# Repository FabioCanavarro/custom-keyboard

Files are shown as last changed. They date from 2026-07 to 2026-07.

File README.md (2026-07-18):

# Fool's Deck

My custom 65% mechanical keyboard designed from scratch for the Hack Club hardware grant.

| Phase | Date(s) | Time Spent |
| :--- | :---: | ---: |
| Brainstorming & Ideation | July 2 | 1 hr 0 mins |
| Physical Layout (KLE) | July 2 | 1 hr 10 mins |
| PCB Design (KiCad) | July 2 – July 4 | 5 hrs 59 mins |
| 3D Modeling (Onshape) | July 4 – July 5 | 4 hrs 25 mins |
| Total Build Time |  | 12 hrs 34 mins (15 hrs 34 mins, check notes below) |

> Note: Post submit, I realized I sent the wrong bom file so I made the bom file and updated the pcb art, I spent around 3 hours in total? (but I forgot to add photos, so Idk if it can be considered)

> Hours spent is based calculated based on the time difference of each screenshots, as normally I take one when starting and when ending.
> For more specific hours/day tracking, head over to the [Journal dump](journaldump.md) file

## Keyboard Layout



## Keyboard Case

### Top View



### Isometric View



## PCB View

### With PCB Art



### Without PCB Art



## Schematic View



## Specs

- Brain: Raspberry Pi Pico (RP2040)

- Switches: Boba U4T

- Keycaps: Blank White DSA

- Forehead: 0.91" OLED screen + EC11 Rotary Encoder (knob)

## What I built

I made a custom 65% layout with a 5-key macro column on the left (for dev shortcuts) and a "forehead" on the top right for an OLED screen and a knob.

For the case, I went with a 3D-printed tray mount design. It has a bottom tub with 6mm pillars for the PCB to sit on, and a 1.5mm top switch plate that drops right in. I also cut a window in the top plate to expose the Pico and leave room to wire up the OLED.

## Why I built it

I type a lot and wanted a board that actually fits my workflow. But mostly, I just wanted to figure out how hardware actually works. I know how to code, but I had no clue how physical switches turn into keypresses or how to use CAD without the physics engine yelling at me. I wanted to build the whole stack from the circuit board up to the plastic case.

## What I learned

This was a massive learning curve.

- I learned that MX switches need exactly 5mm of gap between the PCB and the switch plate to clip in properly. I almost crushed my Pico because I didn't account for the height of the header pins, which is why I ended up cutting a display window for it in the top plate so it could fit.

- When making the switch plate, I kept accidentally extruding 70 floating cubes instead of a solid plate. I learned how to use projection tools to draw a proper boundary wall around the keys so the software knows what's solid plastic and what's empty space.

- This project has also taught me a lot about Computer Aided Design, specifically in OnShape. 

## Next up

While the PCB and parts are shipping, I'm going to write the firmware in Rust using the RMK framework so I can get the OLED visualizer and knob working.

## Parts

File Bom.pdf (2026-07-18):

No. Name | Notes | Quantity | Price Per Unit | Cost | Total | Link
1 | Orpheus Pico Microcontroller | Hack Club provided | 1 | 0 | 0 | https://hackclub.com/
2 | Lord of the Mysteries Cat
3 | GATERON MILKY YELLOW -
4 | 1N4148 Through-hole
| Klein Concept Keycaps | 140+ Pcs Officially Licensed | 1 | 69.9 | 69.9 | https://www.oriloot.com/products/lotm-cat-klein-concept-keycaps-140-pcs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
| Mechanical Switch | Linear switches (5-pin) for 73 keys | 90 | 0.25 | 22.57 | https://www.tokopedia.com/kadesh/gateron-milky-yellow-red-g-pro-lubed-mechanical-switch-yellow-lubed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
| Diodes (10 pcs/batch) | Bought in batches of 10 pcs/1 | 10 | 0.059 | 0.59 | https://shopee.co.id/10pcs-Dioda-diode-1N4448-persamaan-1N4148-IN4148-DO-35-High-speed-switching-i.290887364.22702082048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
5 | EC11 Rotary Encoder | With push button | 1 | 0.53 | 0.53 | https://shopee.co.id/EC11-EC-11-Rotary-Encoder-Digital-Potentiometer-5-pin-Sensor-5V-i.138926279.25109704194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
6 | 0.91 inch I2C OLED display | Pin order: GND-VCC-SCL-SDA | 1 | 2.06 | 2.06 | https://shopee.co.id/0.91-inch-128x32-px-pixels-I2C-IIC-OLED-LCD-Screen-Display-3.3-5Vdc-i.138926279.24014122715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
7 | Stabilizer (6.25u) | 6.25u Stabilizer | 1 | 1.39 | 1.39 | https://www.tokopedia.com/mechkeyboardsid/genuine-cherry-plate-mount-keyboard-stabilizer-6-25u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
8 | Stabilizer (2u) | 2u Stabilizer | 3 | 1.39 | 4.17 | https://www.tokopedia.com/mechkeyboardsid/genuine-cherry-plate-mount-keyboard-stabilizer-6-25u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
9 | M3x10mm Screws | | 20 | 0.024 | 0.48 | https://shopee.co.id/Baut-Verseng-L-M3X10-Baut-JFL-3X10-Countersunk-L-M3-X-10-3-X-10-Socket-Countersunk-Screw-Stainless-SS304-SUS304-A2-70-i.11837378.27576682475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
10 | M3x8mm Screws | | 20 | 0.022 | 0.44 | https://shopee.co.id/DIN-912-1983-Baut-L-Stainless-M3X8-3X8-M3-X-8-3-X-8-Full-Drat-SS304-SUS304-A2-70-Hex-Socket-Head-Cap-Screw-i.11837378.25091564391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
11 | M3x10mmx4mm Heatset Inserts
12 M3x3mmx4mm Heatset | Inserts
| | 20 | 0.07 | 1.4 | https://shopee.co.id/M2-M2.5-M3-M4-M5-M6-M8-Brass-Copper-Thread-Twisted-Knurled-Insert-Nut-Mur-Tanam-Injection-Molding-3d-printing-2mm-3mm-4mm-5mm-6mm-8mm-i.11740388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
| | 20 | 0.057 | 1.14 | https://shopee.co.id/M2-M2.5-M3-M4-M5-M6-M8-Brass-Copper-Thread-Twisted-Knurled-Insert-Nut-Mur-Tanam-Injection-Molding-3d-printing-2mm-3mm-4mm-5mm-6mm-8mm-i.11740388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
13 | Rotary Encoder Knob | 1 | 0.42 | 0.42 | https://shopee.co.id/Knob-Potensiometer-Baut-MF-A05-A-05-Rotary-Encoder-Switch-Potensio-Potentio-Meter-Knop-Adjust-Putar-i.342972164.24939610328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
14 | Custom KiCad PCB (JLCPCB) (Comes in batches of 5 pcs) | FR4 / HASL Lead-Free (Comes in batches of 5 pcs) (Delivery Price included) | 5 | 38.79 | 38.79 | | https://jlcpcb.com/
15 | Custom 3D Printed Case & Plate | JLCPCB 9600 Resin (tub) & Imagine black (top) (Delivery Price included) | 1 | 50.49 | 50.49 | | https://jlcpcb.com/3d-printing
| | | | | | 190.47

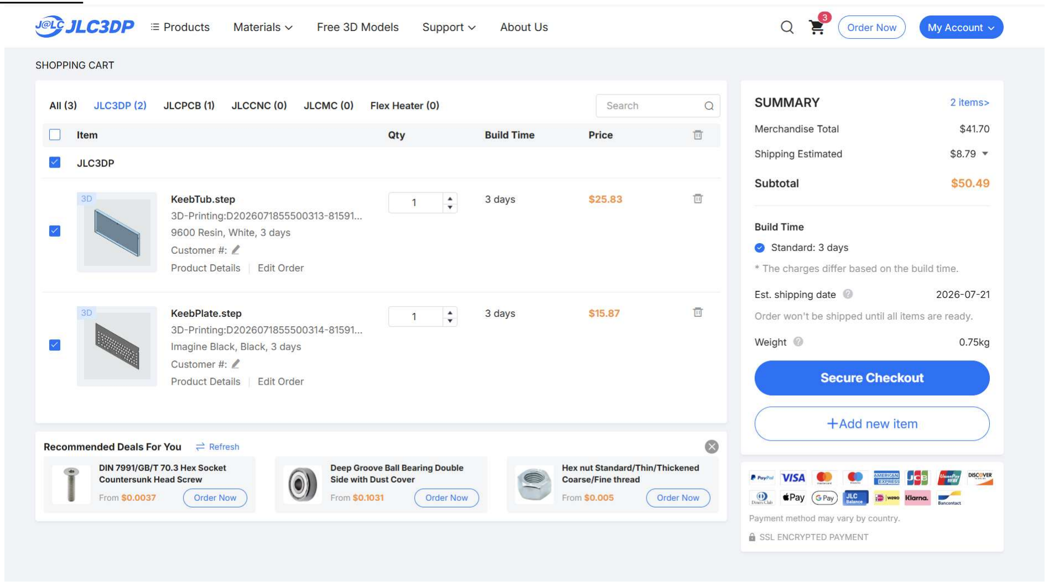
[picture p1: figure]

3D model price

PCB price

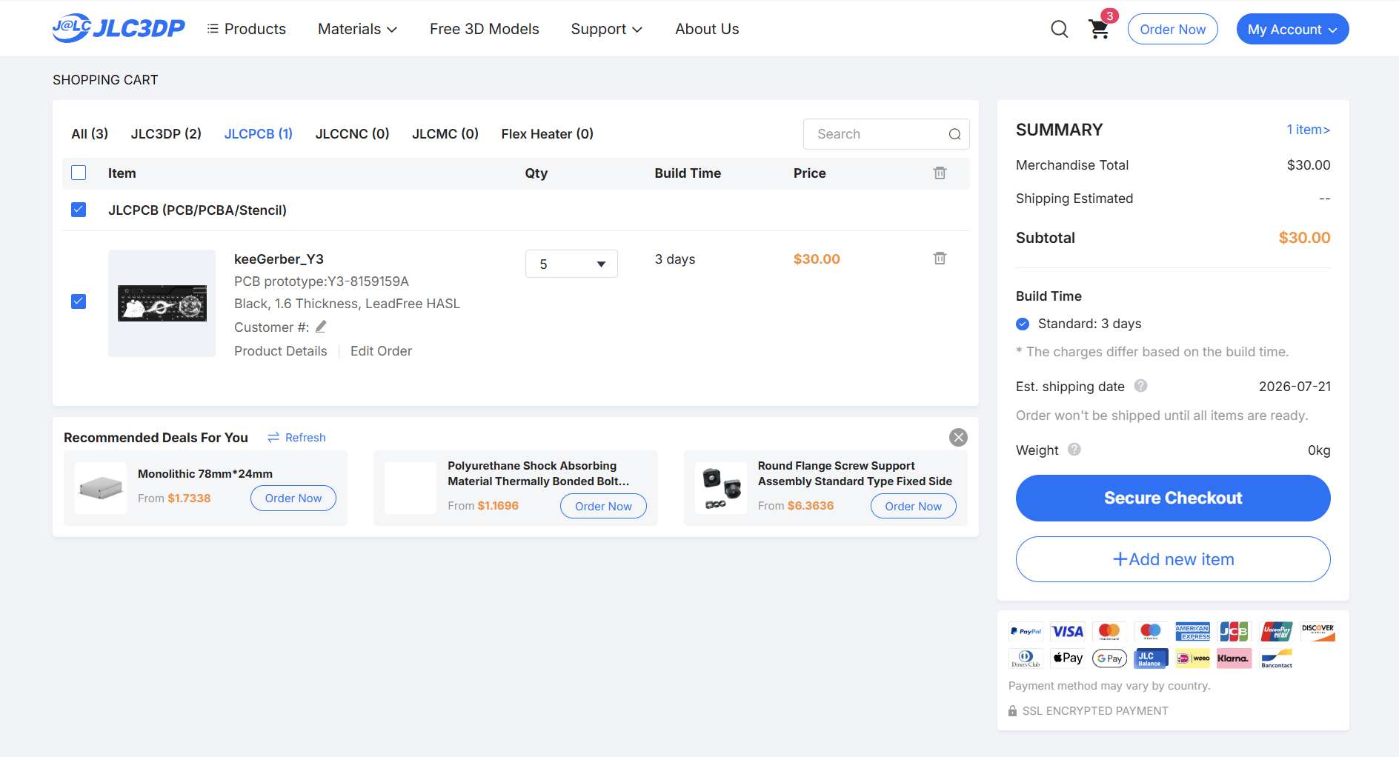
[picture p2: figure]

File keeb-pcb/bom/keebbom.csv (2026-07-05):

Id | Designator | Footprint | Quantity | Designation | Supplier and ref
1 | A1 | RaspberryPi_Pico_Common_THT | 1 | RaspberryPi_Pico
2 | D1, D2, D3, D4, D5, D6, D7, D8, D9, D10, D11, D12, D13, D14, D15, D16, D17, D18, D19, D20, D21, D22, D23, D24, D25, D26, D27, D28, D29, D30, D31, D32, D33, D34, D35, D36, D37, D38, D39, D40, D41, D42, D43, D44, D45, D46, D47, D48, D49, D50, D51, D52, D53, D54, D55, D56, D57, D58, D59, D60, D61, D62, D63, D64, D65, D66, D67, D68, D69, D70, D71, D72, D73 | D_DO-35_SOD27_P7.62mm_Horizontal | 73 | 1N4148
3 | ENC1 | RotaryEncoder_Alps_EC11E-Switch_Vertical_H20mm | 1 | RotaryEncoder_Switch
4 | S1 | STAB_MX_2u | 1 | MX_stab
5 | S2 | STAB_MX_P_6.25u | 1 | MX_stab
6 | S3, S4 | STAB_MX_2.25u | 2 | MX_stab
7 | SW1, SW2, SW3, SW4, SW5, SW6, SW7, SW8, SW9, SW10, SW11, SW12, SW13, SW14, SW15, SW16, SW17, SW18, SW19, SW20, SW21, SW22, SW23, SW24, SW25, SW26, SW27, SW28, SW29, SW30, SW31, SW32, SW33, SW34, SW35, SW36, SW37, SW38, SW39, SW40, SW41, SW42, SW43, SW44, SW45, SW46, SW47, SW48, SW49, SW50, SW51, SW52, SW53, SW54, SW55, SW56, SW57, SW58, SW59, SW60, SW61, SW62, SW63, SW64, SW65, SW66, SW67, SW68, SW69, SW70, SW71, SW72, SW73 | SW_MX_1u | 73 | SW_Push
8 | U1 | ER_OLEDM0.91_1x-I2C | 1 | ER_OLEDM0.91_1x-I2C
1 | A1 | RaspberryPi_Pico_Common_THT | 1 | RaspberryPi_Pico
2 | D1, D2, D3, D4, D5, D6, D7, D8, D9, D10, D11, D12, D13, D14, D15, D16, D17, D18, D19, D20, D21, D22, D23, D24, D25, D26, D27, D28, D29, D30, D31, D32, D33, D34, D35, D36, D37, D38, D39, D40, D41, D42, D43, D44, D45, D46, D47, D48, D49, D50, D51, D52, D53, D54, D55, D56, D57, D58, D59, D60, D61, D62, D63, D64, D65, D66, D67, D68, D69, D70, D71, D72, D73 | D_DO-35_SOD27_P7.62mm_Horizontal | 73 | 1N4148
3 | ENC1 | RotaryEncoder_Alps_EC11E-Switch_Vertical_H20mm | 1 | RotaryEncoder_Switch
4 | S1 | STAB_MX_2u | 1 | MX_stab
5 | S2 | STAB_MX_P_6.25u | 1 | MX_stab
6 | S3, S4 | STAB_MX_2.25u | 2 | MX_stab
7 | SW1, SW2, SW3, SW4, SW5, SW6, SW7, SW8, SW9, SW10, SW11, SW12, SW13, SW14, SW15, SW16, SW17, SW18, SW19, SW20, SW21, SW22, SW23, SW24, SW25, SW26, SW27, SW28, SW29, SW30, SW31, SW32, SW33, SW34, SW35, SW36, SW37, SW38, SW39, SW40, SW41, SW42, SW43, SW44, SW45, SW46, SW47, SW48, SW49, SW50, SW51, SW52, SW53, SW54, SW55, SW56, SW57, SW58, SW59, SW60, SW61, SW62, SW63, SW64, SW65, SW66, SW67, SW68, SW69, SW70, SW71, SW72, SW73 | SW_MX_1u | 73 | SW_Push
8 | U1 | ER_OLEDM0.91_1x-I2C | 1 | ER_OLEDM0.91_1x-I2C

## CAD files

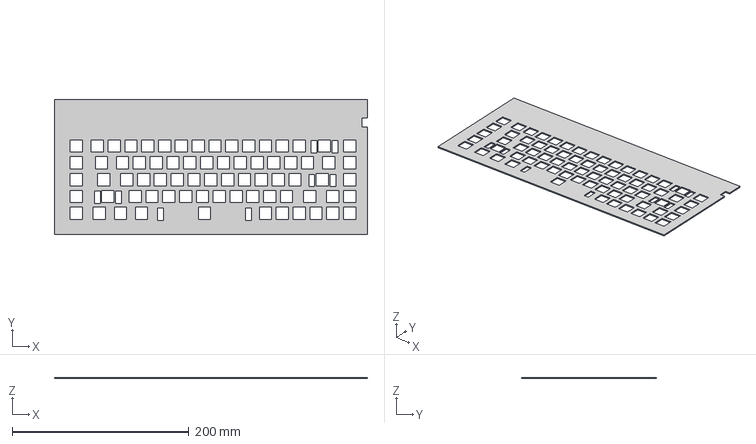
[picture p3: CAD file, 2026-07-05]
3dModel/KeebPlate.step
354.5 x 152.5 x 1.50 mm

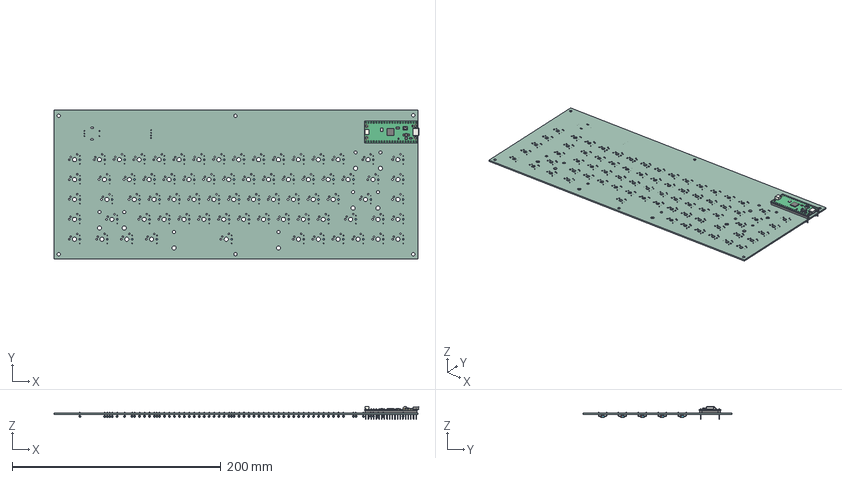
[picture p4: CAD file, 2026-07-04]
keeb-pcb/.step
349.5 x 142.5 x 12.8 mm
RaspberryPi_Pico_H_Module_KiCad
RaspberryPi_Pico_Header_DIP-40_H2.54mm_KiCad
D_DO-35_SOD27_P7.62mm_Horizontal x 73
kee2D1F_PCB

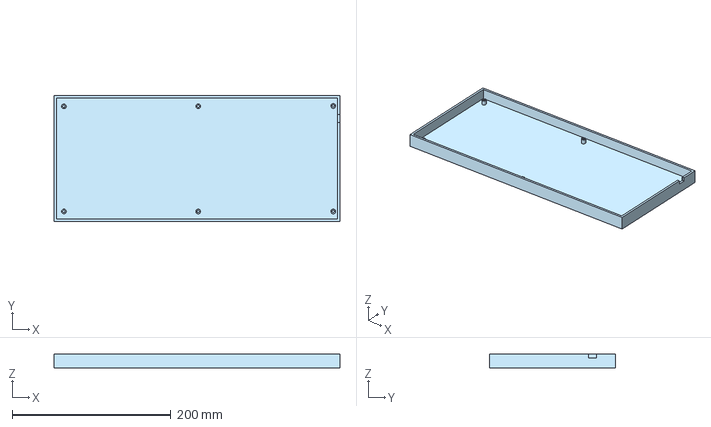
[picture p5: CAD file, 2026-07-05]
3dModel/KeebTub.step
360.5 x 158.5 x 18.0 mm

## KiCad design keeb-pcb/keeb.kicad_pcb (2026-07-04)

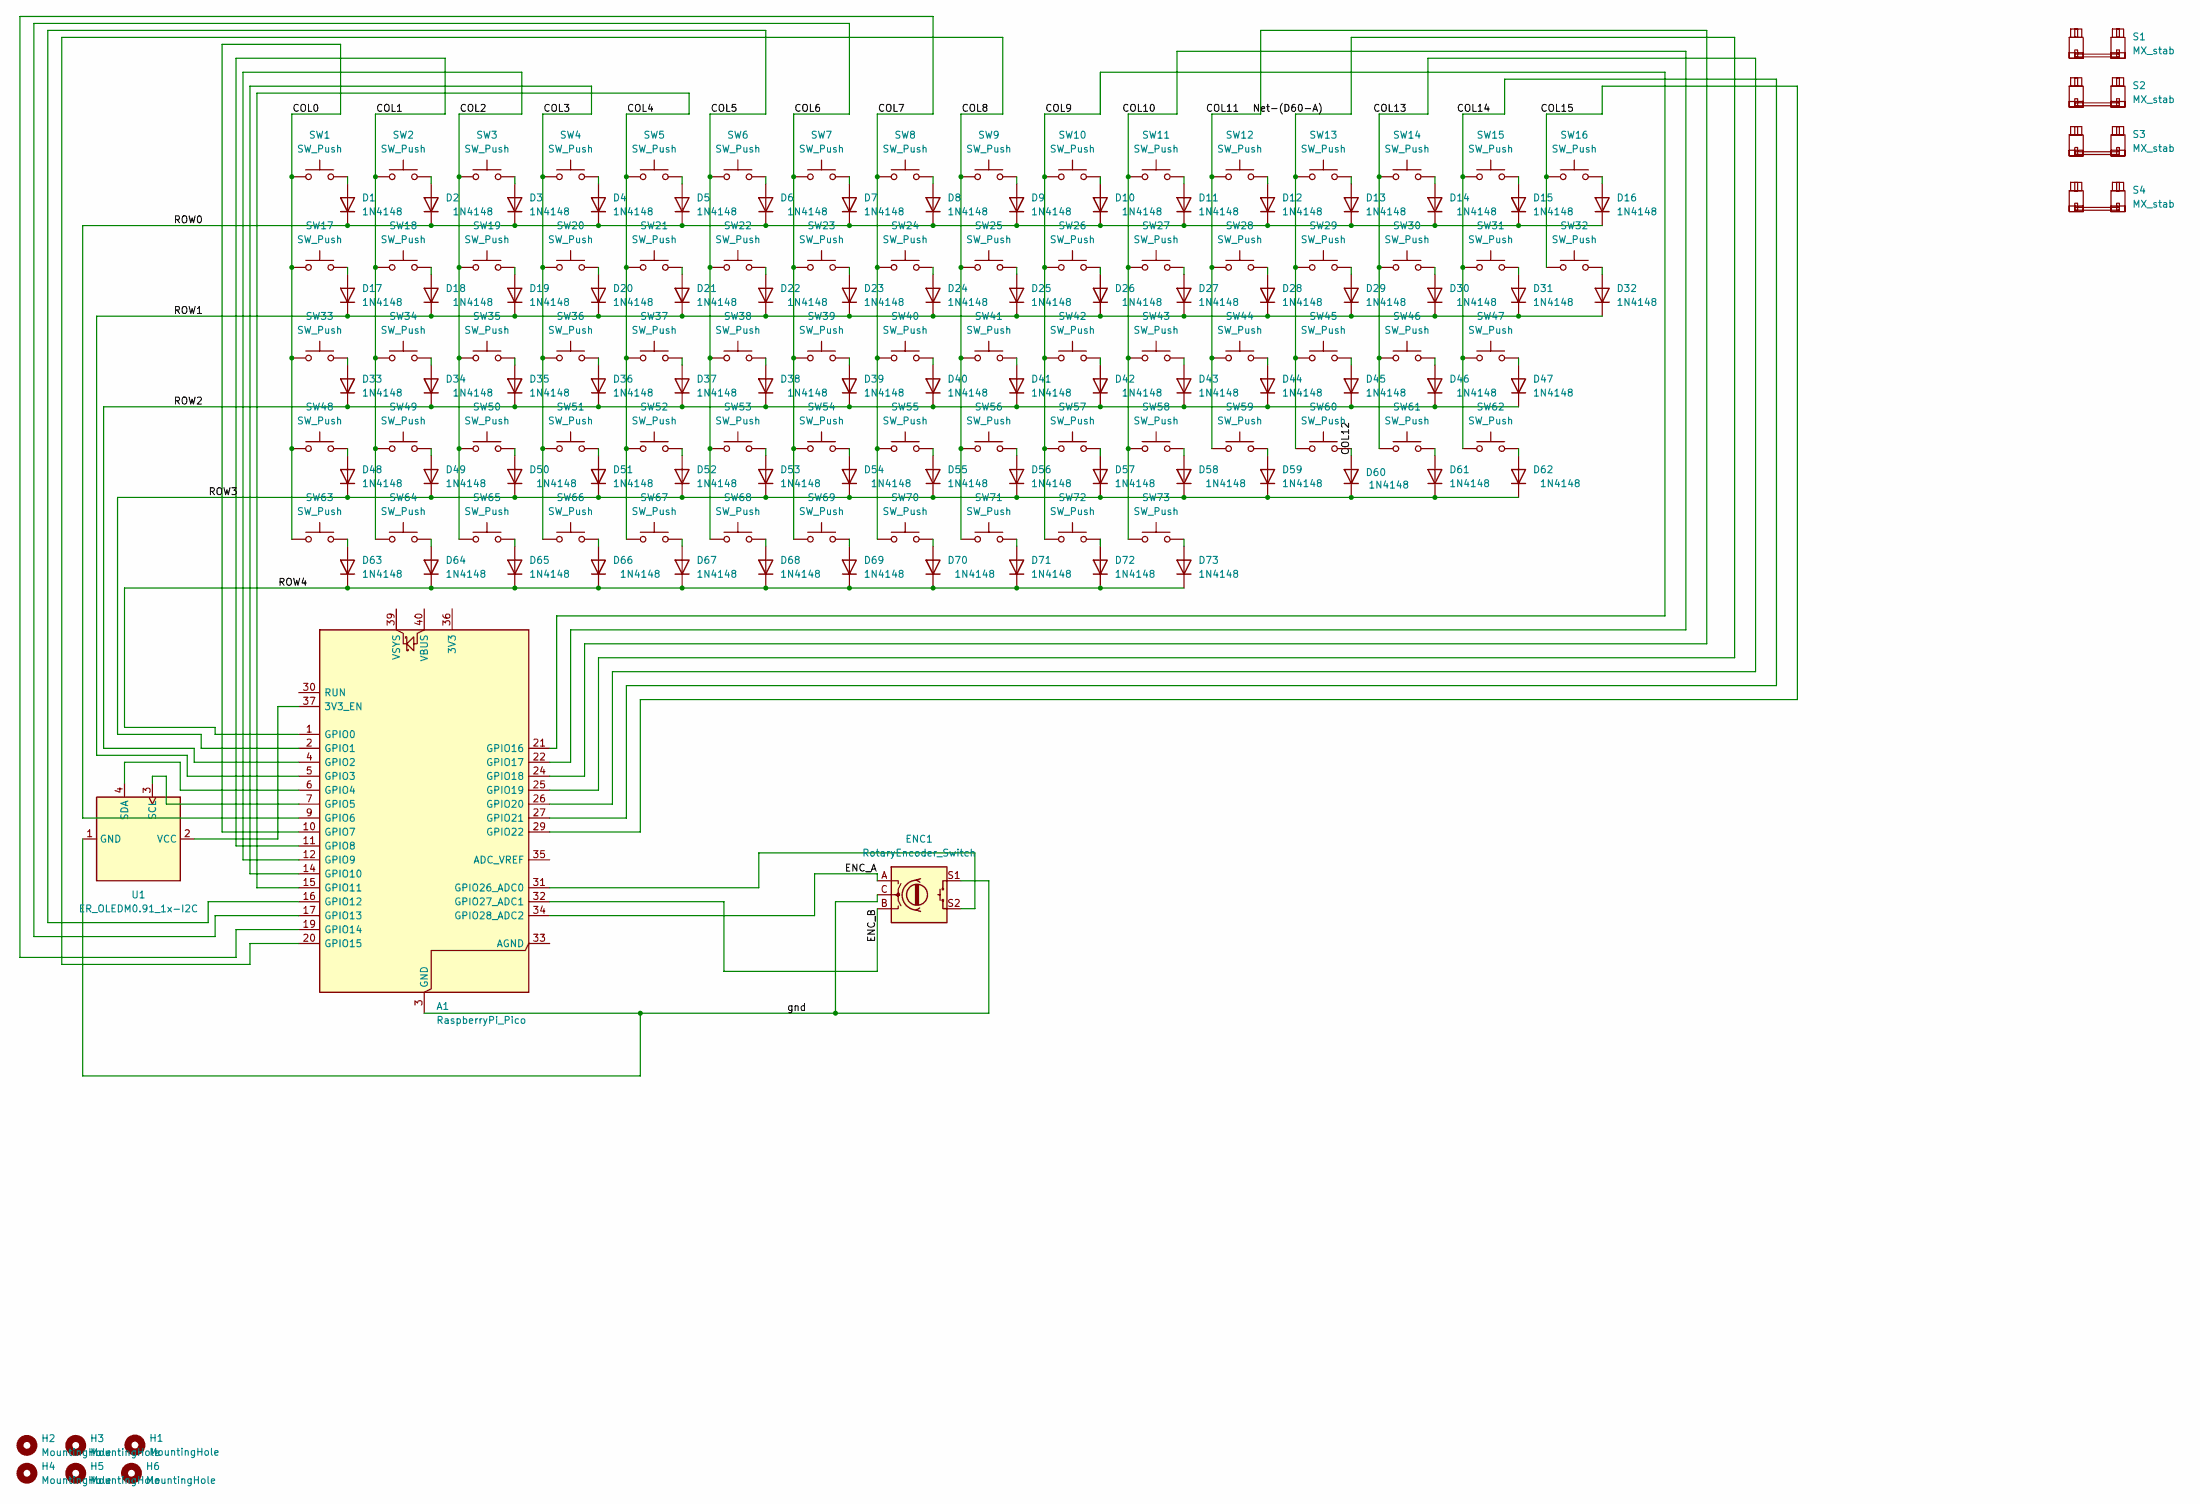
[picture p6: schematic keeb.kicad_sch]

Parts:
A1: RaspberryPi_Pico; RaspberryPi_Pico_Common_THT
D1, D2, D3, D4, D5, D6, D7, D8, D9, D10, D11, D12, D13, D14, D15, D16, D17, D18, D19, D20, D21, D22, D23, D24, D25, D26, D27, D28, D29, D30, D31, D32, D33, D34, D35, D36, D37, D38, D39, D40, D41, D42, D43, D44, D45, D46, D47, D48, D49, D50, D51, D52, D53, D54, D55, D56, D57, D58, D59, D60, D61, D62, D63, D64, D65, D66, D67, D68, D69, D70, D71, D72, D73: 1N4148; D_DO-35_SOD27_P7.62mm_Horizontal
ENC1: RotaryEncoder_Switch; RotaryEncoder_Alps_EC11E-Switch_Vertical_H20mm
H1, H2, H3, H4, H5, H6: MountingHole; MountingHole_3.2mm_M3
S1: MX_stab; STAB_MX_2u
S2: MX_stab; STAB_MX_P_6.25u
S3, S4: MX_stab; STAB_MX_2.25u
SW1, SW2, SW3, SW4, SW5, SW6, SW7, SW8, SW9, SW10, SW11, SW12, SW13, SW14, SW15, SW16, SW17, SW18, SW19, SW20, SW21, SW22, SW23, SW24, SW25, SW26, SW27, SW28, SW29, SW30, SW31, SW32, SW33, SW34, SW35, SW36, SW37, SW38, SW39, SW40, SW41, SW42, SW43, SW44, SW45, SW46, SW47, SW48, SW49, SW50, SW51, SW52, SW53, SW54, SW55, SW56, SW57, SW58, SW59, SW60, SW61, SW62, SW63, SW64, SW65, SW66, SW67, SW68, SW69, SW70, SW71, SW72, SW73: SW_Push; SW_MX_1u
U1: ER_OLEDM0.91_1x-I2C

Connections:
/COL0: A1.10 (GPIO7), SW1.1, SW17.1, SW33.1, SW48.1, SW63.1
/COL1: A1.11 (GPIO8), SW2.1, SW18.1, SW34.1, SW49.1, SW64.1
/COL2: A1.12 (GPIO9), SW3.1, SW19.1, SW35.1, SW50.1, SW65.1
/COL3: A1.14 (GPIO10), SW4.1, SW20.1, SW36.1, SW51.1, SW66.1
/COL4: A1.15 (GPIO11), SW5.1, SW21.1, SW37.1, SW52.1, SW67.1
/COL5: A1.16 (GPIO12), SW6.1, SW22.1, SW38.1, SW53.1, SW68.1
/COL6: A1.17 (GPIO13), SW7.1, SW23.1, SW39.1, SW54.1, SW69.1
/COL7: A1.19 (GPIO14), SW8.1, SW24.1, SW40.1, SW55.1, SW70.1
/COL8: A1.20 (GPIO15), SW9.1, SW25.1, SW41.1, SW56.1, SW71.1
/COL9: A1.21 (GPIO16), SW10.1, SW26.1, SW42.1, SW57.1, SW72.1
/COL10: A1.22 (GPIO17), SW11.1, SW27.1, SW43.1, SW58.1, SW73.1
/COL11: A1.24 (GPIO18), SW12.1, SW28.1, SW44.1, SW59.1
/COL13: A1.26 (GPIO20), SW14.1, SW30.1, SW46.1, SW61.1
/COL14: A1.27 (GPIO21), SW15.1, SW31.1, SW47.1, SW62.1
/COL15: A1.29 (GPIO22), SW16.1, SW32.1
/ENC_A: A1.34 (GPIO28_ADC2), ENC1.A
/ENC_B: A1.32 (GPIO27_ADC1), ENC1.B
/ROW0: A1.9 (GPIO6), D1.1 (K), D2.1 (K), D3.1 (K), D4.1 (K), D5.1 (K), D6.1 (K), D7.1 (K), D8.1 (K), D9.1 (K), D10.1 (K), D11.1 (K), D12.1 (K), D13.1 (K), D14.1 (K), D15.1 (K), D16.1 (K)
/ROW1: A1.5 (GPIO3), D17.1 (K), D18.1 (K), D19.1 (K), D20.1 (K), D21.1 (K), D22.1 (K), D23.1 (K), D24.1 (K), D25.1 (K), D26.1 (K), D27.1 (K), D28.1 (K), D29.1 (K), D30.1 (K), D31.1 (K), D32.1 (K)
/ROW2: A1.4 (GPIO2), D33.1 (K), D34.1 (K), D35.1 (K), D36.1 (K), D37.1 (K), D38.1 (K), D39.1 (K), D40.1 (K), D41.1 (K), D42.1 (K), D43.1 (K), D44.1 (K), D45.1 (K), D46.1 (K), D47.1 (K)
/ROW3: A1.2 (GPIO1), D48.1 (K), D49.1 (K), D50.1 (K), D51.1 (K), D52.1 (K), D53.1 (K), D54.1 (K), D55.1 (K), D56.1 (K), D57.1 (K), D58.1 (K), D59.1 (K), D60.1 (K), D61.1 (K), D62.1 (K)
/ROW4: A1.1 (GPIO0), D63.1 (K), D64.1 (K), D65.1 (K), D66.1 (K), D67.1 (K), D68.1 (K), D69.1 (K), D70.1 (K), D71.1 (K), D72.1 (K), D73.1 (K)
/gnd: A1.3 (GND), A1.8 (GND), A1.13 (GND), A1.18 (GND), A1.23 (GND), A1.28 (GND), A1.38 (GND), ENC1.C, ENC1.S1, U1.1 (GND)
unnamed: A1.37 (3V3_EN), U1.2 (VCC)
unnamed: A1.6 (GPIO4), U1.4 (SDA)
unnamed: A1.7 (GPIO5), U1.3 (SCL)
unnamed: A1.31 (GPIO26_ADC0), ENC1.S2
unnamed: D1.2 (A), SW1.2
unnamed: D2.2 (A), SW2.2
unnamed: D3.2 (A), SW3.2
unnamed: D4.2 (A), SW4.2
unnamed: D5.2 (A), SW5.2
unnamed: D6.2 (A), SW6.2
unnamed: D7.2 (A), SW7.2
unnamed: D8.2 (A), SW8.2
unnamed: D9.2 (A), SW9.2
unnamed: D10.2 (A), SW10.2
unnamed: D11.2 (A), SW11.2
unnamed: D12.2 (A), SW12.2
unnamed: D13.2 (A), SW13.2
unnamed: D14.2 (A), SW14.2
unnamed: D15.2 (A), SW15.2
unnamed: D16.2 (A), SW16.2
unnamed: D17.2 (A), SW17.2
unnamed: D18.2 (A), SW18.2
unnamed: D19.2 (A), SW19.2
unnamed: D20.2 (A), SW20.2
unnamed: D21.2 (A), SW21.2
unnamed: D22.2 (A), SW22.2
unnamed: D23.2 (A), SW23.2
unnamed: D24.2 (A), SW24.2
unnamed: D25.2 (A), SW25.2
unnamed: D26.2 (A), SW26.2
unnamed: D27.2 (A), SW27.2
unnamed: D28.2 (A), SW28.2
unnamed: D29.2 (A), SW29.2
unnamed: D30.2 (A), SW30.2
unnamed: D31.2 (A), SW31.2
unnamed: D32.2 (A), SW32.2
unnamed: D33.2 (A), SW33.2
unnamed: D34.2 (A), SW34.2
unnamed: D35.2 (A), SW35.2
unnamed: D36.2 (A), SW36.2
unnamed: D37.2 (A), SW37.2
unnamed: D38.2 (A), SW38.2
unnamed: D39.2 (A), SW39.2
unnamed: D40.2 (A), SW40.2
unnamed: D41.2 (A), SW41.2
unnamed: D42.2 (A), SW42.2
unnamed: D43.2 (A), SW43.2
unnamed: D44.2 (A), SW44.2
unnamed: D45.2 (A), SW45.2
unnamed: D46.2 (A), SW46.2
unnamed: D47.2 (A), SW47.2
unnamed: D48.2 (A), SW48.2
unnamed: D49.2 (A), SW49.2
unnamed: D50.2 (A), SW50.2
unnamed: D51.2 (A), SW51.2
unnamed: D52.2 (A), SW52.2
unnamed: D53.2 (A), SW53.2
unnamed: D54.2 (A), SW54.2
unnamed: D55.2 (A), SW55.2
unnamed: D56.2 (A), SW56.2
unnamed: D57.2 (A), SW57.2
unnamed: D58.2 (A), SW58.2
unnamed: D59.2 (A), SW59.2
unnamed: D61.2 (A), SW61.2
unnamed: D62.2 (A), SW62.2
unnamed: D63.2 (A), SW63.2
unnamed: D64.2 (A), SW64.2
unnamed: D65.2 (A), SW65.2
unnamed: D66.2 (A), SW66.2
unnamed: D67.2 (A), SW67.2
unnamed: D68.2 (A), SW68.2
unnamed: D69.2 (A), SW69.2
unnamed: D70.2 (A), SW70.2
unnamed: D71.2 (A), SW71.2
unnamed: D72.2 (A), SW72.2
unnamed: D73.2 (A), SW73.2

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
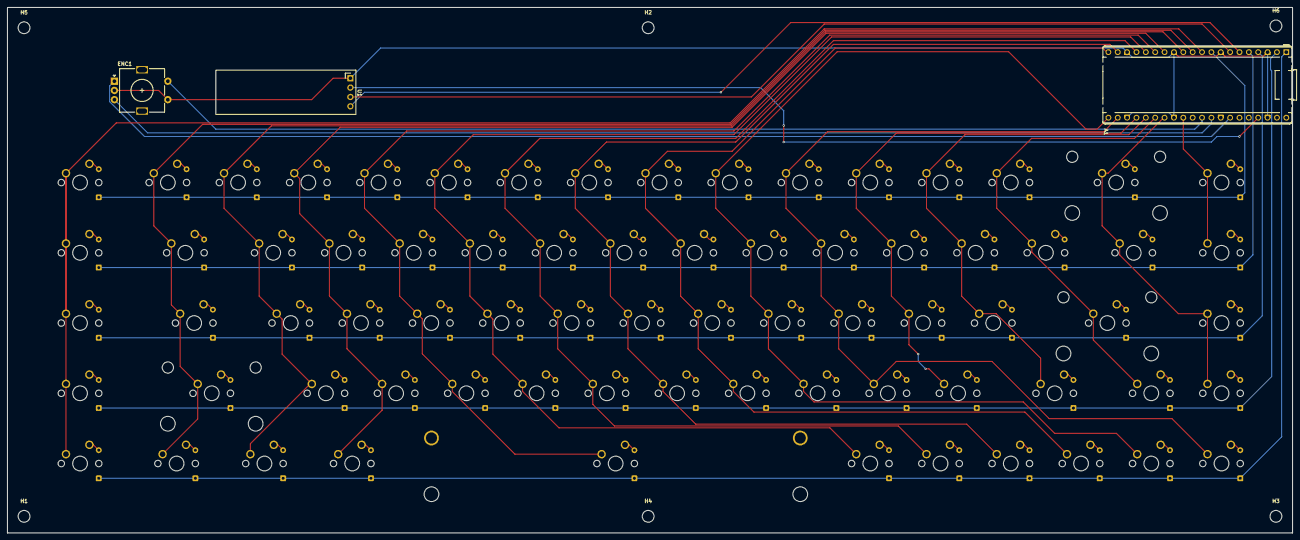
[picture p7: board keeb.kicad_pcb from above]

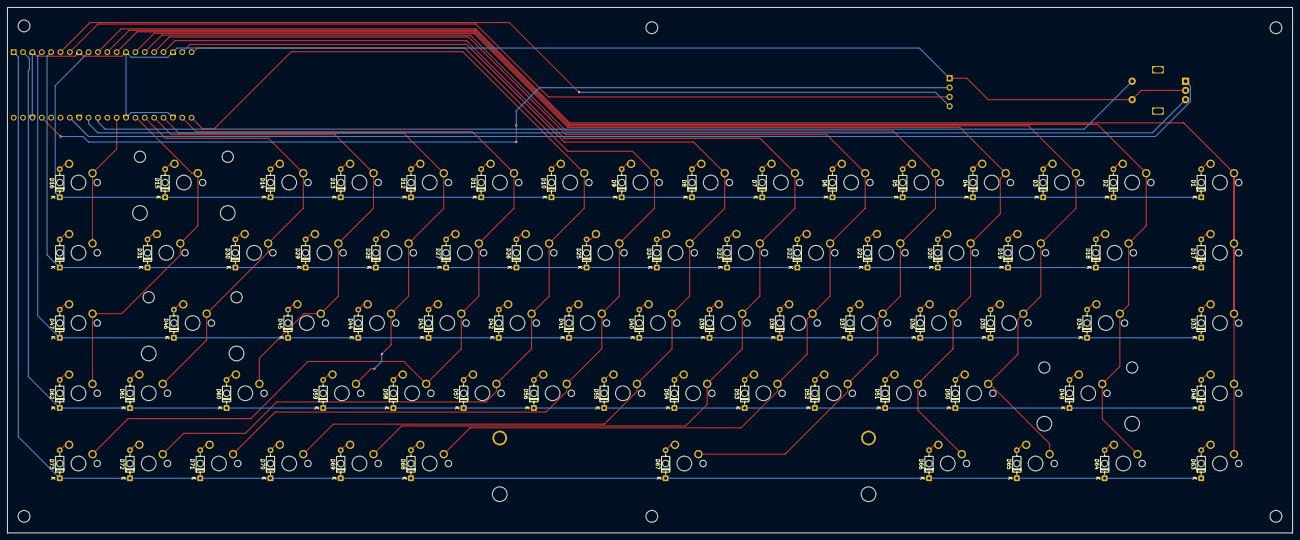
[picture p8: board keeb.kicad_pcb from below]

Board: 2 copper layers, 348.5 x 142.5 mm, 159 parts (73 on the bottom side), 101 nets.

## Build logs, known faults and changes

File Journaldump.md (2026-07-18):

# Journal

## Brainstorming (July 2nd) (1 hour)

Spent around 1 hour brainstorming (with my brother and my friend lmao) about the features that my keyboard will have:

1. A macro column on the left side

Having a dedicated column of 5 macro keys on the far left side of the board would give me the ability to use shortcuts easily lmao.

> I havent actually seen many keyboards that have this kind of macro key, but i do remember the small device that is like a board?

2. A column isolated just for a display and a rotary encoder on the most right side

Where and why it is use?

- 0.91" SSD1306 OLED Display on the top of the column, displaying any one of these things (ex: Music visualizer, hardware data like temperature or usage, or timer) 

- EC11 Rotary Encoder, position either above or below the screen, it can be rotated infinitely and it has a built-in push-button (so I don't need to waste board space on a separate physical button). It will most likely be used for cycling menus in the OLED display.

> Honestly I am most excited for the music visualizer 

3. Physical Aesthetics & Switches

- Aesthetic: I am going for a sleek and smooth kind of look on my keyboard

- Switches: High-quality Tactile/Linear switches (e.g., Boba U4T or similar).

> I love the sound of linear switches, but I still yearn for the distinct physical bump felt when pressing tactile switches.

- Keycaps: White blank DSA keycaps (?)

- Underglow: SK6812 MINI-E addressable RGB LEDs for a subtle ambient glow.

> Damn formatting all my thoughts into 1 clear information really took around 10 mins sheesh.

---

## The physical Layout design (July 2nd) (1 hour +, so lets say 1 hour, 10 minutes)

> Aint no way i just spent 1+ hour on something as simple as this bro 😭🥲

### 1st prototype 



> I think I nailed the initial aesthetics, but idk how
> Btw I forgot to upload it here the 1st prototype, since I normally send it to my whatsapp for storage... 😅

### Final draft (?)



> OLED Screen is not to scale (Idk how to get the measurement of 0.91")

> I feel like the 1st prototype had too little colour variation, and also I forgot to add the Oled display, and I also edited the keys label (?) to be in various locations depending on the location of each individual key lmao

---

## Designing the PCB (July 2nd, 3rd, and 4th)

### July 2nd (35 minutes)



> I just got the 4 basic thing placed and installed some plugins along the way heheheh



Its been 32 Minutes

> I Finished it halfway then I realized, I was placing buses and not wires, that's why it wasn't connecting...

### July 3rd (3 hours and 5 minute)



> Its the day after, I added some things in 5 minute, I shall put it here to start the time recording of today lmao



> Updated footprint and updated pcb from schematic



> Just realized I got 73 keys not 80...



> Since kicad-kbplacer is allowed



> I used kicad-kbplacer to speed up the placing of the keys with little to no error, then comes the hard part, I did not know how much gap to give anything. So I firstly tried to put it however I see fit, then after trying a lot of measurement, I realized all this time, I could've just used the ruler tool and alter the specific x,y coordinates instead of using my intuition...



> I finally routed everything, like my schematic was wrong from the very beginning, I didn't account for the fact that some keys took more space than others in the same row, leading to less keys in the row



> Finished routing all the pins

### July 4th (2 hours and 19 minutes)



> Clocking in for today, Now I will start Connecting the pins



> Only this far in did I realize how much I messed up my schematic routing lmao, thats why it took a long time



> I am so cooked 😭



> Anddd, Fixed all error

## 3d Model (4th and 5th July)

### July 4th ( 2 hours and 38 minutes)

> Idk when I started onshape, so i took the 2nd picture time, which is `6:35` - `7:18` then added with `9:32` - `11:27`



> Now editing it in onshape



> Finally finished the switch plate



> Aligning Is hard as hell (gonna go take a break)



> Came back, spent 10 minute aligning it, by coordinate shifts hehehe



> Damn Extruding it makes it look fancy



> Built the base floor finally bruh, Like onshape just keeps throwing random error msg at me



> 3d model is genuienly the hardest part, imma just rest for now

## July 5th (1 hour + 47 minute)



> Gonna restart, since i think i messed up



> Almost fixed it, just 1 small mistake



> Finally finished everything, Holy onshape is hard, but this project has made me learnt the 20% of the things needed to do many things

## July 17th & 18th (3 hours)

> I kinda forgot to add screenshots oof, all i can do is prob provide screenshots of my search history which is filled with searches on the materials



> Based on this slack message, It has been said that we can order our own keycaps sets

So I have decided to go for my a custom keycap set

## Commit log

2026-07-02 Update PCB design section with image and notes
    Added an image and updated notes on PCB design progress.
2026-07-03 Update Journal with new image and PCB changes
    Added an image and updated footprint and PCB from schematic.
2026-07-03 Update Journal with images and key placement insights
    Added images and reflections on using kicad-kbplacer for key placement.
2026-07-04 Added all the file after finishing pcb design
    [.step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]
2026-07-05 Added all the file after finishing 3d cad design got the bom and gerver and all
    [.step, KeebPlate.step, KeebTub.step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]
2026-07-12 Expand README with keyboard case and circuitry details
    Added keyboard case and circuitry sections with images.
2026-07-17 Updated the pcb by pcb art
    [keeb-B_Cu.gbl, keeb-B_Mask.gbs, keeb-B_Paste.gbp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]
2026-07-18 Added the correct bom and bom pdf
    [bom.csv, keebbom.csv, keebbom_fixed.csv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]
2026-07-18 Revise total build time in README
    Updated total build time to reflect additional hours spent on BOM file and PCB art.
